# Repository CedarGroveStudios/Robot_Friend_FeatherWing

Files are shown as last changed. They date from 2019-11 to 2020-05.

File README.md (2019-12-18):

# Cedar Grove Robot Friend FeatherWing

### _A passive FeatherWing adapter for stacking an Adafruit PyBadge or PyGamer onto a Crickit FeatherWing. Includes a prototyping area for custom circuitry and sensors._

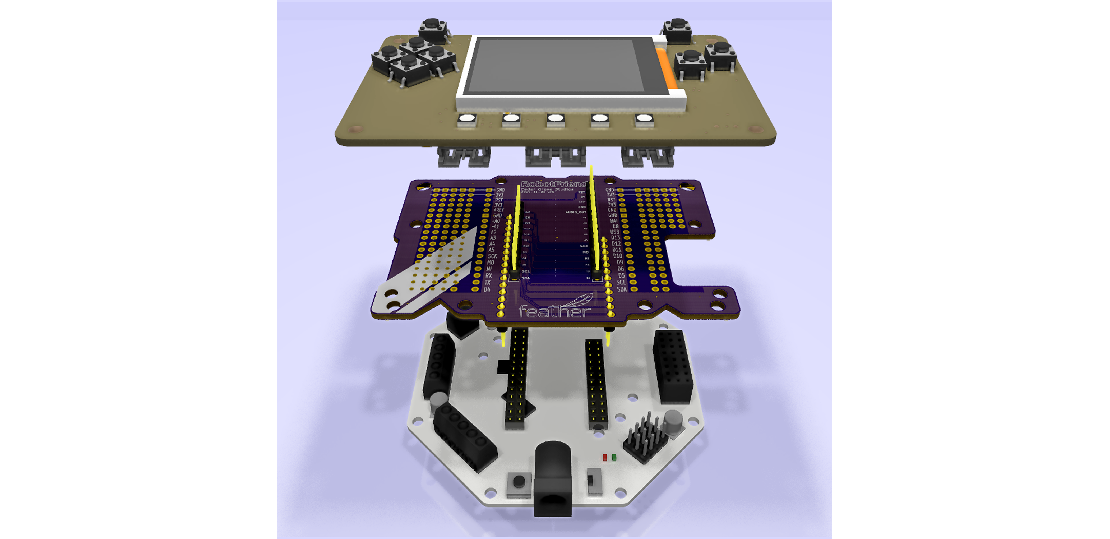
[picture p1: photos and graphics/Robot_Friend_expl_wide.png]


Perched on the top of a robot chassis, the Cedar Grove Robot Friend FeatherWing passively connects the FeatherWing connections of a PyBadge or PyGamer device with a Crickit FeatherWing. The Crickit provides 3.3V power to the attached PyBadge/PyGamer. All Feather signals are interconnected to accommodate custom alterations to the Crickit module, such as support for IRQ/Busy or sensor modifications.

The Cedar Grove Robot Friend includes a prototype area and a breakout of all Feather pins for further cusomization.

For use ONLY with the Crickit FeatherWing and compatible Feather MCU boards. To date, it has only been tested with the PyGamer and PyBadge. Double-check pin compatibility if you plan to attach or stack other Feather devices.

#### Caution:
The Crickit is capable of providing up to 150mA of 3.3-volt power to the attached PB/PG Feather. In normal operation without any of the NeoPixels lighted or the use of the built-in speaker amplifier, the PB/PG will draw about 60mA from the Crickit's internal 3.3-volt regulator. 

When the PB/PG is powered only by the Crickit via the Feather 3V pin, the PB/PG 3.3v regulator is reverse-biased by the Crickit-supplied +3.3 volts. The AP2112-3.3 regulator has an intrinsic MOSFET diode between its output and input that conducts when reverse-biased, raising the voltage of the input pin to the same as the output pin less the forward voltage drop of the diode. What that means is that 5-volt components like the PB/PG's NeoPixels and Stemma connectors will have approximately +3.2 volts available for operation. The PB/PG NeoPixels seem to work with the lower voltage, but might not be 100% reliable. 

Since the reverse-biased "feature" of the PB/PG's internal regulator is not documented in the datasheet, it's probably a good idea to limit use of the PB/PG NeoPixels when stacked on the Crickit via the Robot Friend FeatherWing. If you need to brightly light the PB/PG NeoPixels or connect a speaker to the on-board amplifier, consider adding a small LiPo battery directly to the PB/PG or just use the Crickit's on-board NeoPixel or drive a string via the Crickit's external NeoPixel connector. If a louder speaker is needed, use the Crickit's speaker output since the Crickit amplifier is not connected to the 3.3-volt power supply.

Intrinsic MOSFET Diode Discussion: https://www.digikey.com/en/articles/techzone/2016/sep/the-significance-of-the-intrinsic-body-diodes-inside-mosfets

OSH Park project: 

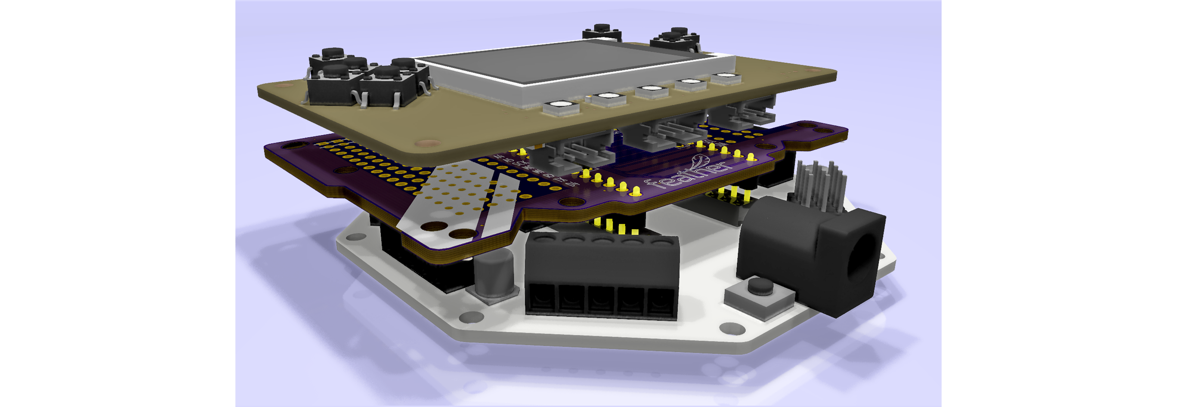
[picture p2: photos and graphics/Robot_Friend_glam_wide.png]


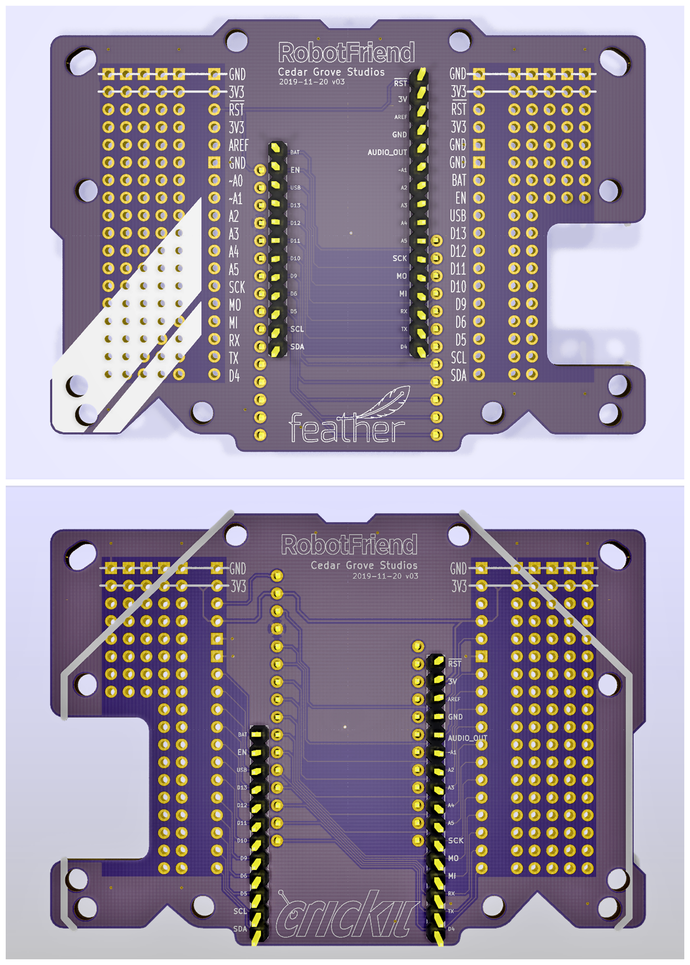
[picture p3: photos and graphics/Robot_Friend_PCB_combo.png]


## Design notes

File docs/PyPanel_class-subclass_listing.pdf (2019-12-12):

### PyPanel Class-Subclass Listing

board | i2c | panel | display | crickit | terminalio | label | displayio | turtle | stemma (list)
A0 | deinit | acceleration | auto_brightness | continuous_servo_1 | FONT | displayio Bitmap | addshape | device
A1 | readfrom_into | auto_dim_display | brightness | continuous_servo_2 | Terminal | Label | ColorConverter | back | object
A2 | scan | bitmap_qr | bus | continuous_servo_3 | | | Disiplay | backward | description
A3 | try_lock | brightness | height | continuous_servo_4 | | | FourWire | bk
A4 | unlock | button | refresh_soon | dc_motor_1 | | | Group | circle
A5 | writeto | BUTTON_A | show | dc_motor_2 | | | OnDiskBitmap | clear
A6 | | BUTTON_B | wait_for_frame | drive_1 | | | Palette | degrees
A7 | | BUTTON_DOWN | width | drive_2 | | | ParallelBus | dot
A8 | | BUTTON_LEFT | | drive_3 | | | release_displays | down
A9 | | BUTTON_RIGHT | | drive_4 | | | Shape | fd
ACCELEROMETER_INTERRUPT | | BUTTON_SELECT | | drive_stepper_motor | | | TileGrid | forward
BUTTON_CLOCK | | BUTTON_START | | feather_drive_1 | | | | getpen
BUTTON_LATCH | | BUTTON_UP | | feather_drive_2 | | | | goto
BUTTON_OUT | | joystick (PyGamer only) | | feather_drive_3 | | | | heading
D0 | | has_joystick | | feather_drive_4 | | | | home
D1 | | light | | feather_drive_stepper_motor | | | | ht
D10 | | pixels | | init_neopixel | | | | isdown
D11 | | play_file | | neopixel | | | | left
D12 | | play_tone | | onboard_pixel | | | | lt
D13 | | show_badge | | reset | | | | pd
D2 | | show_business_card | | seesaw | | | | pencolor
D3 | | show_qr_code | | servo_1 | | | | pendown
D4 | | show_terminal | | servo_2 | | | | pensize
D5 | | start_tone | | servo_3 | | | | penup
D6 | | stop_tone | | servo_4 | | | | position
D7 | | | | SIGNAL1 | | | | pu
D8 | | | | SIGNAL2 | | | | radians
D9 | | | | SIGNAL3 | | | | right
DISPLAY | | | | SIGNAL4 | | | | rt
I2C | | | | SIGNAL5 | | | | seth
LIGHT | | | | SIGNAL6 | | | | setheading
MISO | | | | SIGNAL7 | | | | setpos
MOSI | | | | SIGNAL8 | | | | setposition
NEOPIXEL | | | | stepper_motor | | | | setx
RX | | | | touch_1 | | | | sety
SCK | | | | touch_2 | | | | st
SCL | | | | touch_3 | | | | turtlesize
SDA | | | | touch_4 | | | | up
SPEAKER | | | | | | | | width
SPEAKER_ENABLE | | | | | | | | xcor
SPI | | | | | | | | ycor
TFT_CS
TFT_DC
TFT_LITE
TFT_MOSI
TFT_RST
TFT_SCK
TX
UART
12/12/2019 11:58 AM | PyPanel_class-subclass_listing.xlsx top_level | Page 1 of 1

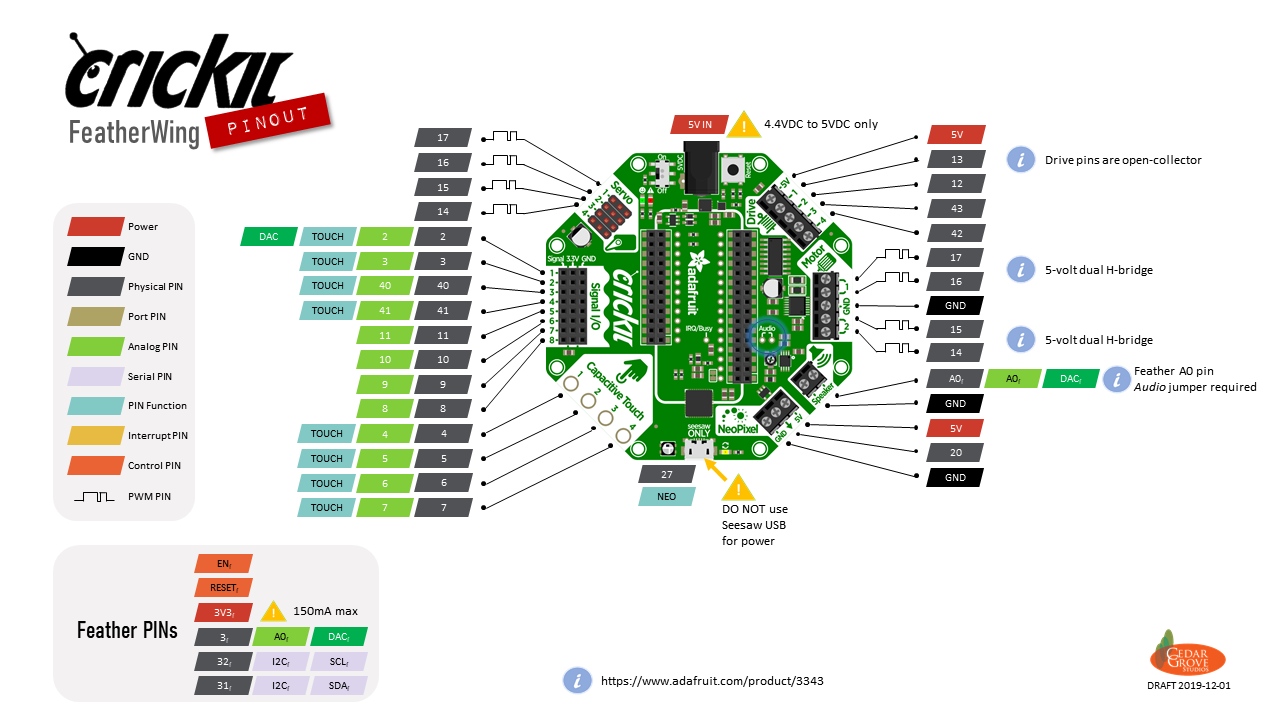
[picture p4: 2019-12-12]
docs/Crickit_FeatherWing_pinout.png

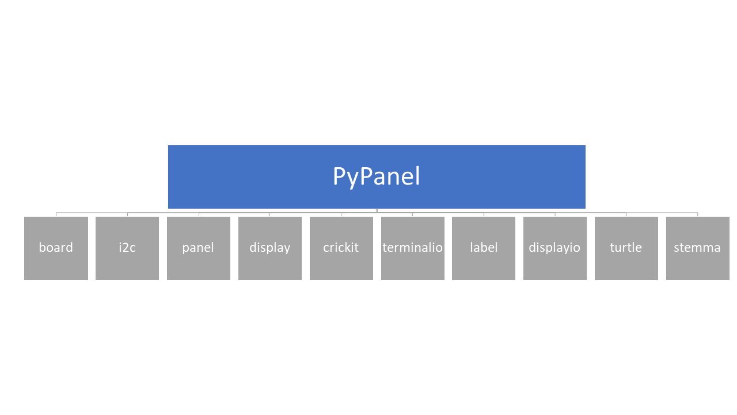
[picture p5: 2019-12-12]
docs/PyPanel_feature_hierarchy.png

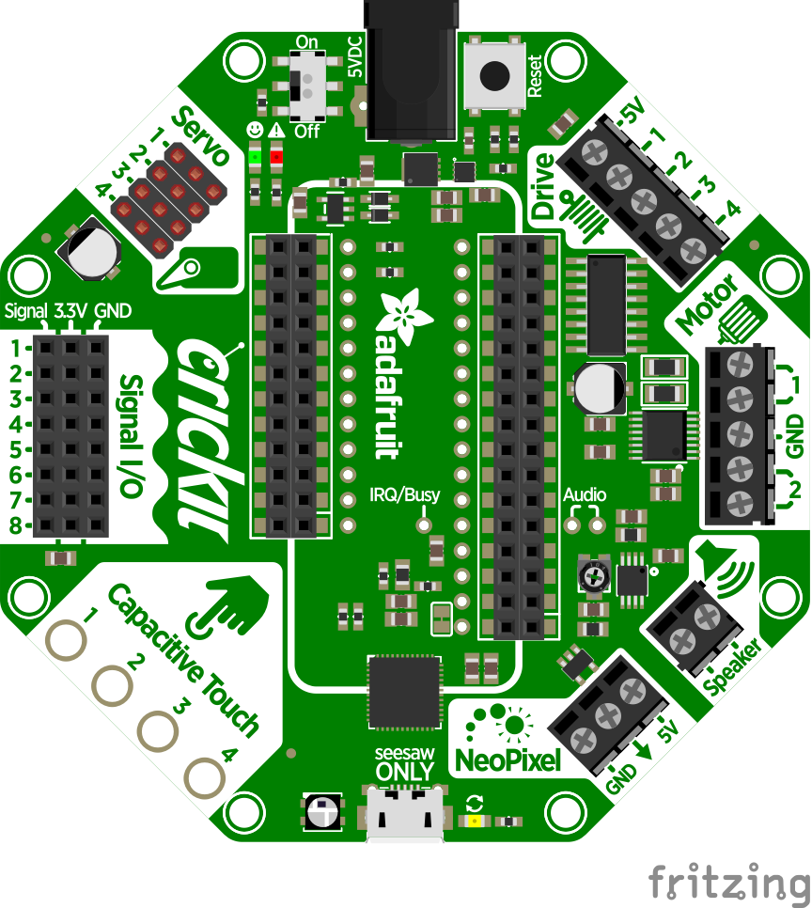
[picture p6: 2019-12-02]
docs/Untitled Sketch_bb.png

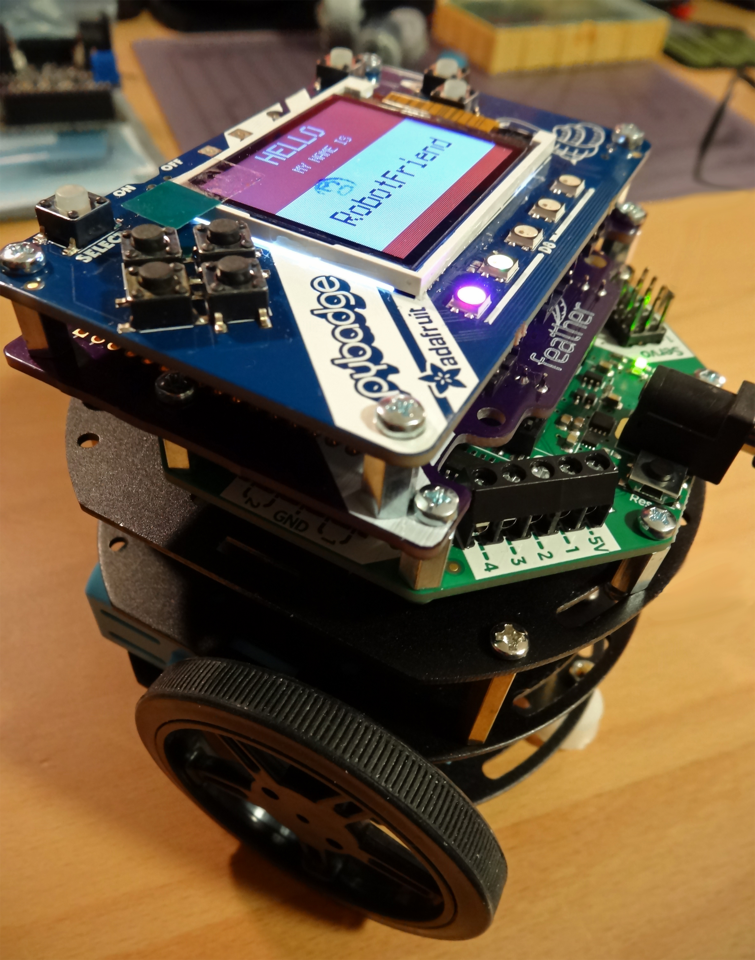
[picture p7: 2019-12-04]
photos and graphics/DSC05909a.jpg

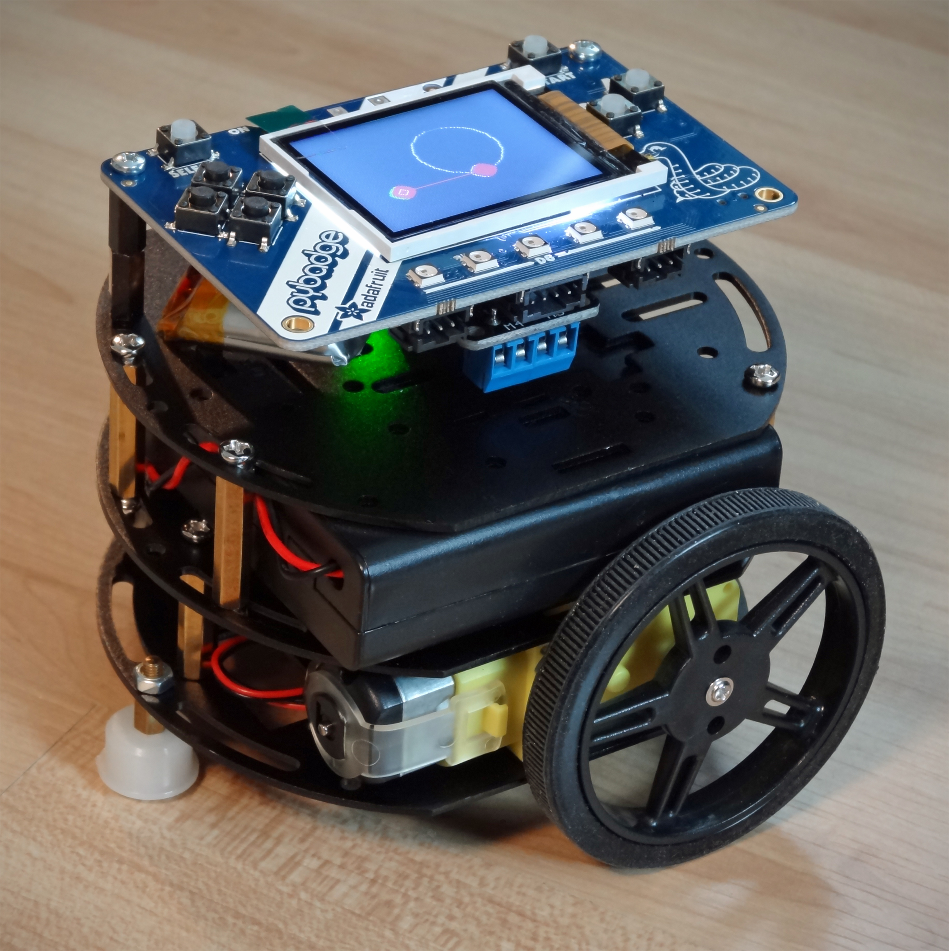
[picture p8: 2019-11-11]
photos and graphics/DSC05840a lores.jpg

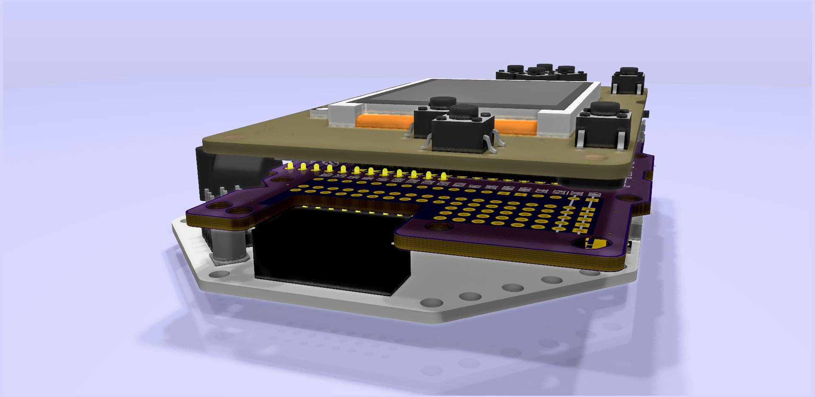
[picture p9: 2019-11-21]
photos and graphics/Robot_Friend_cutout.png

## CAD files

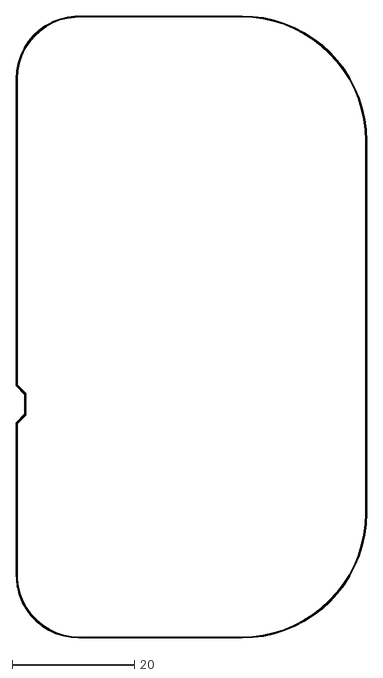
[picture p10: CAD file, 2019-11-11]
photos and graphics/Adafruit PyGamer-Edge.Cuts.dxf
57.3 x 101.8

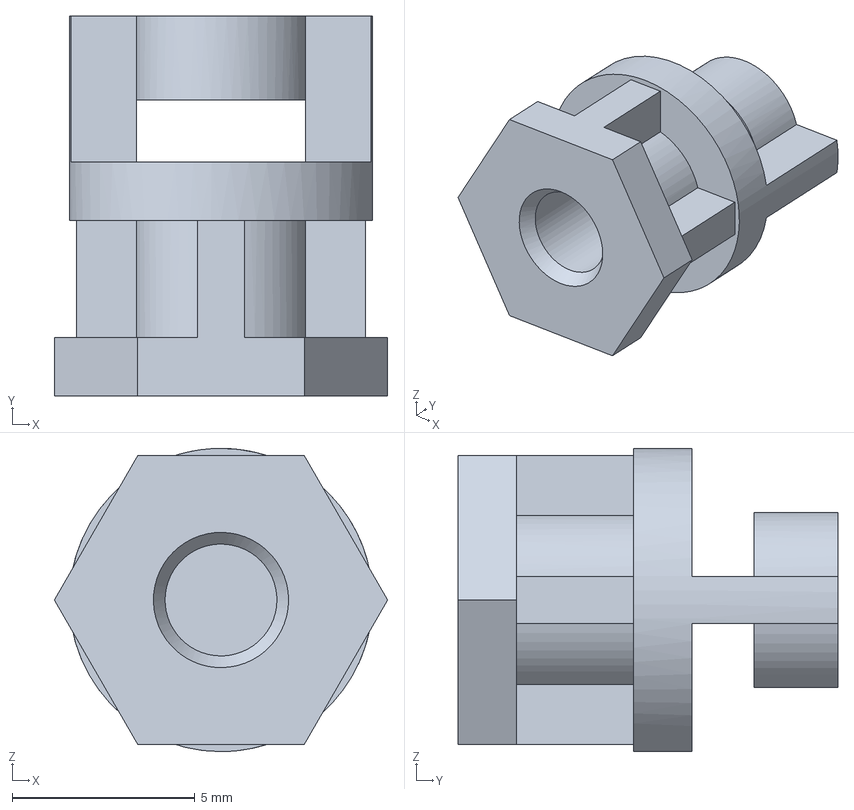
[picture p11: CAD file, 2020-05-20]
TCEHCBS board fastener/TCEHCBS-4-01.stp
9.12 x 10.4 x 8.30 mm

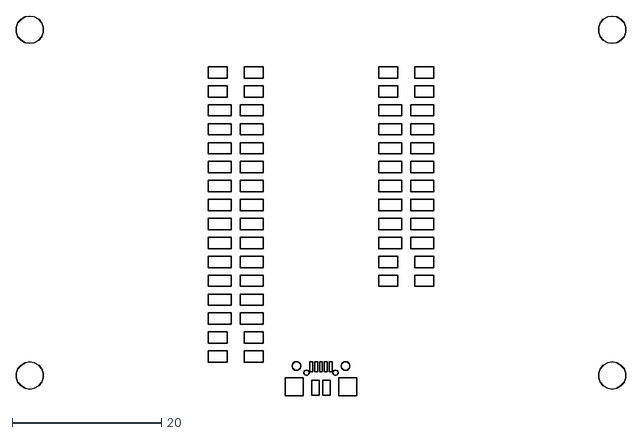
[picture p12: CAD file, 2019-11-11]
photos and graphics/Adafruit PyBadge-Bottom.dxf
81.7 x 50.9

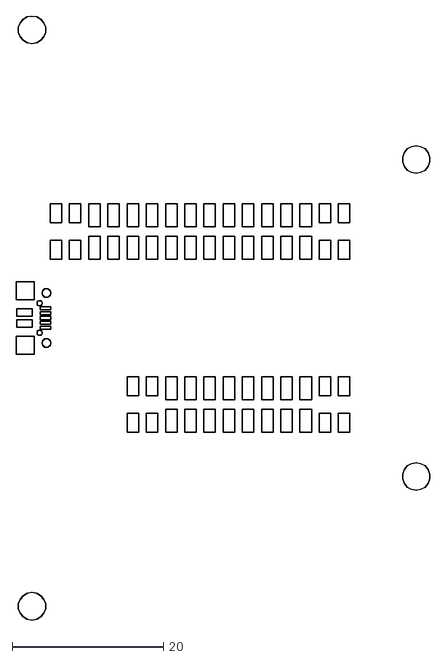
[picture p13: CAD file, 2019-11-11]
photos and graphics/Adafruit PyGamer-Bottom.dxf
54.7 x 79.9

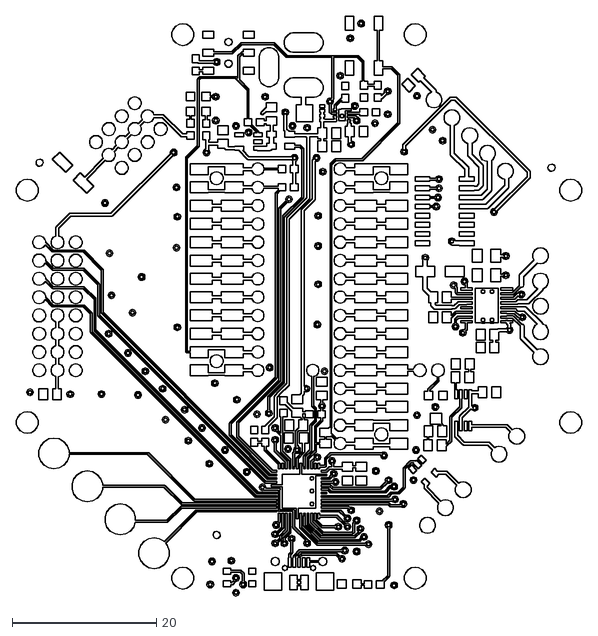
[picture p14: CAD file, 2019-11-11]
photos and graphics/Adafruit Crickit FeatherWing-Top.dxf
78.4 x 80.5

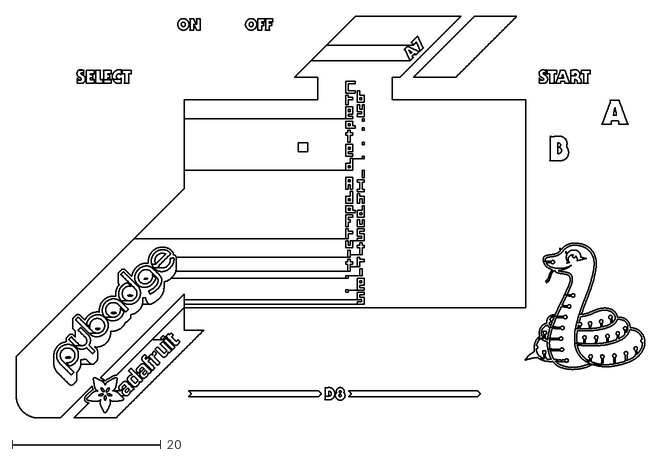
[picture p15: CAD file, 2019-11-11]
photos and graphics/Adafruit PyBadge-Dwgs.User.dxf
84.6 x 54.1

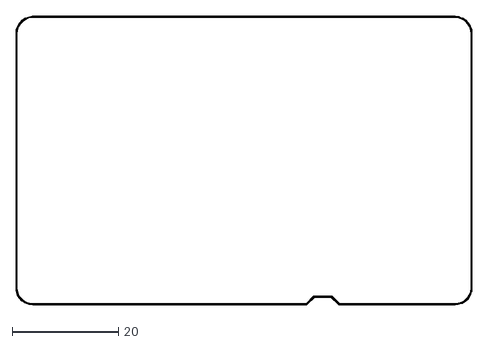
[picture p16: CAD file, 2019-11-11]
photos and graphics/Adafruit PyBadge-Edge.Cuts.dxf
85.9 x 54.3

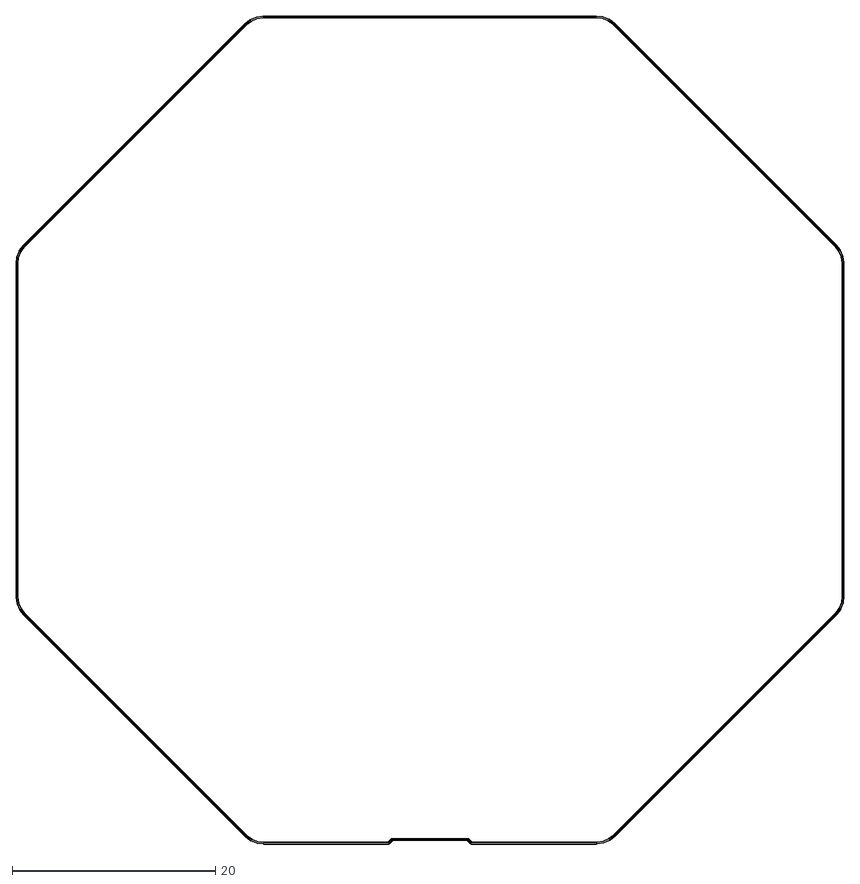
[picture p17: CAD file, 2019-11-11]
photos and graphics/Adafruit Crickit FeatherWing-Edge.Cuts.dxf
81.4 x 81.4

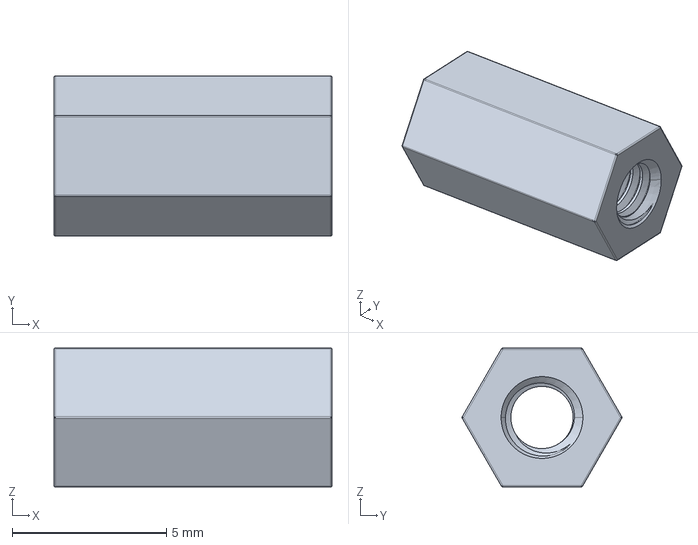
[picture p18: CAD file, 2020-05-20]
Mouser_M1256-2545-N-9mm_M2.5_standoff/M1256-2545-N-Choose_material.stp
9.00 x 5.18 x 4.50 mm

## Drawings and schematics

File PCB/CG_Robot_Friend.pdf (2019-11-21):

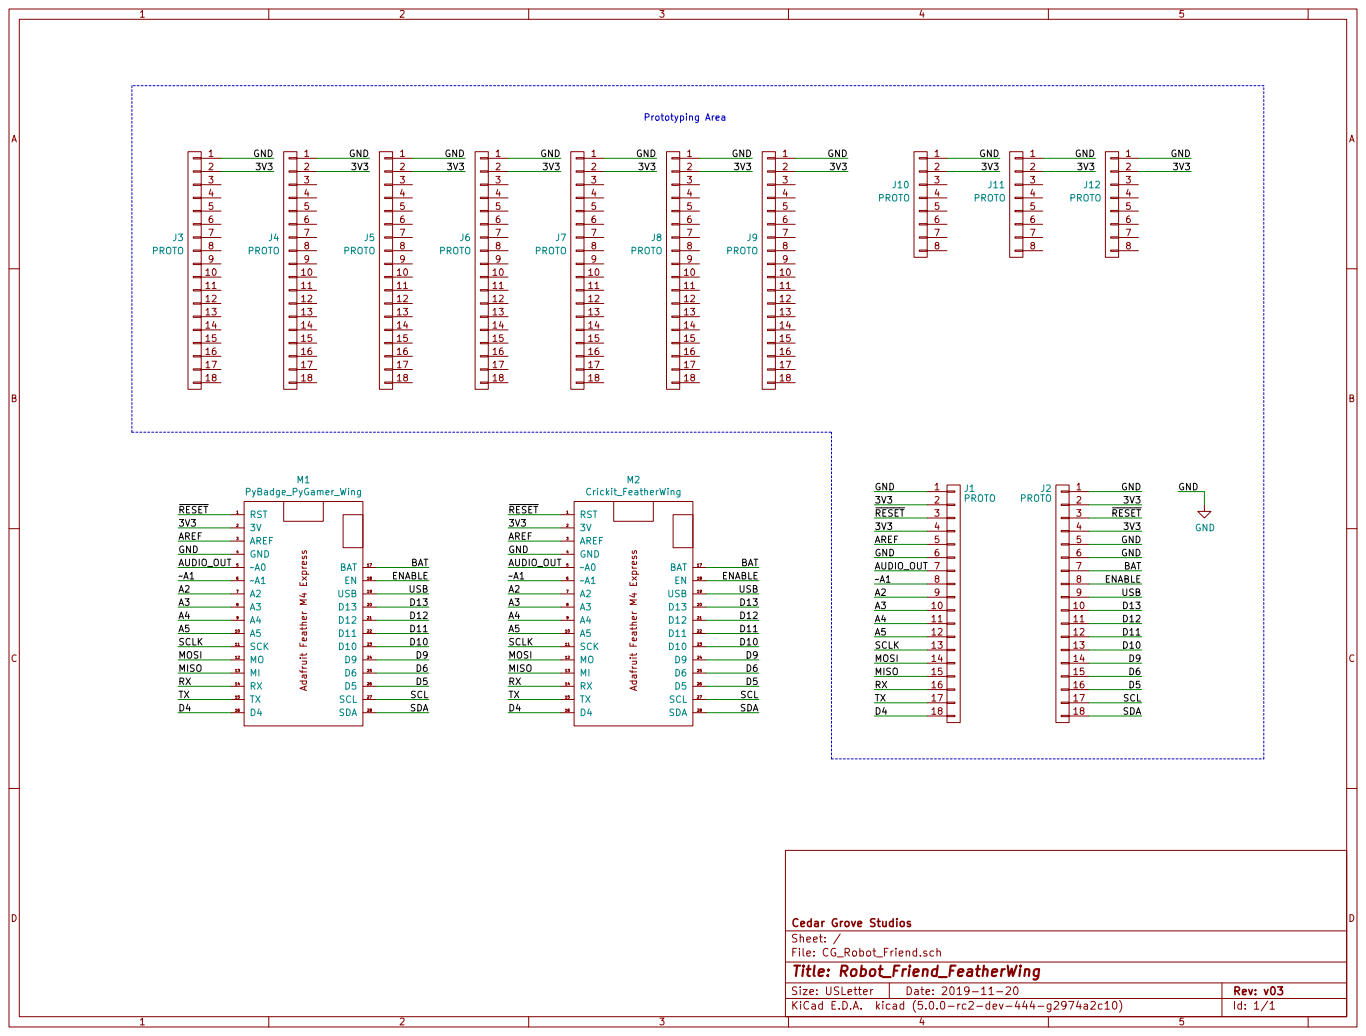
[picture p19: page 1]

SCL ENABLE D13 USB D11 D12 D9 D10 D5 D6 BAT MOSI SCLK

File: CG_Robot_Friend.sch Sheet: / Cedar Grove Studios SDA

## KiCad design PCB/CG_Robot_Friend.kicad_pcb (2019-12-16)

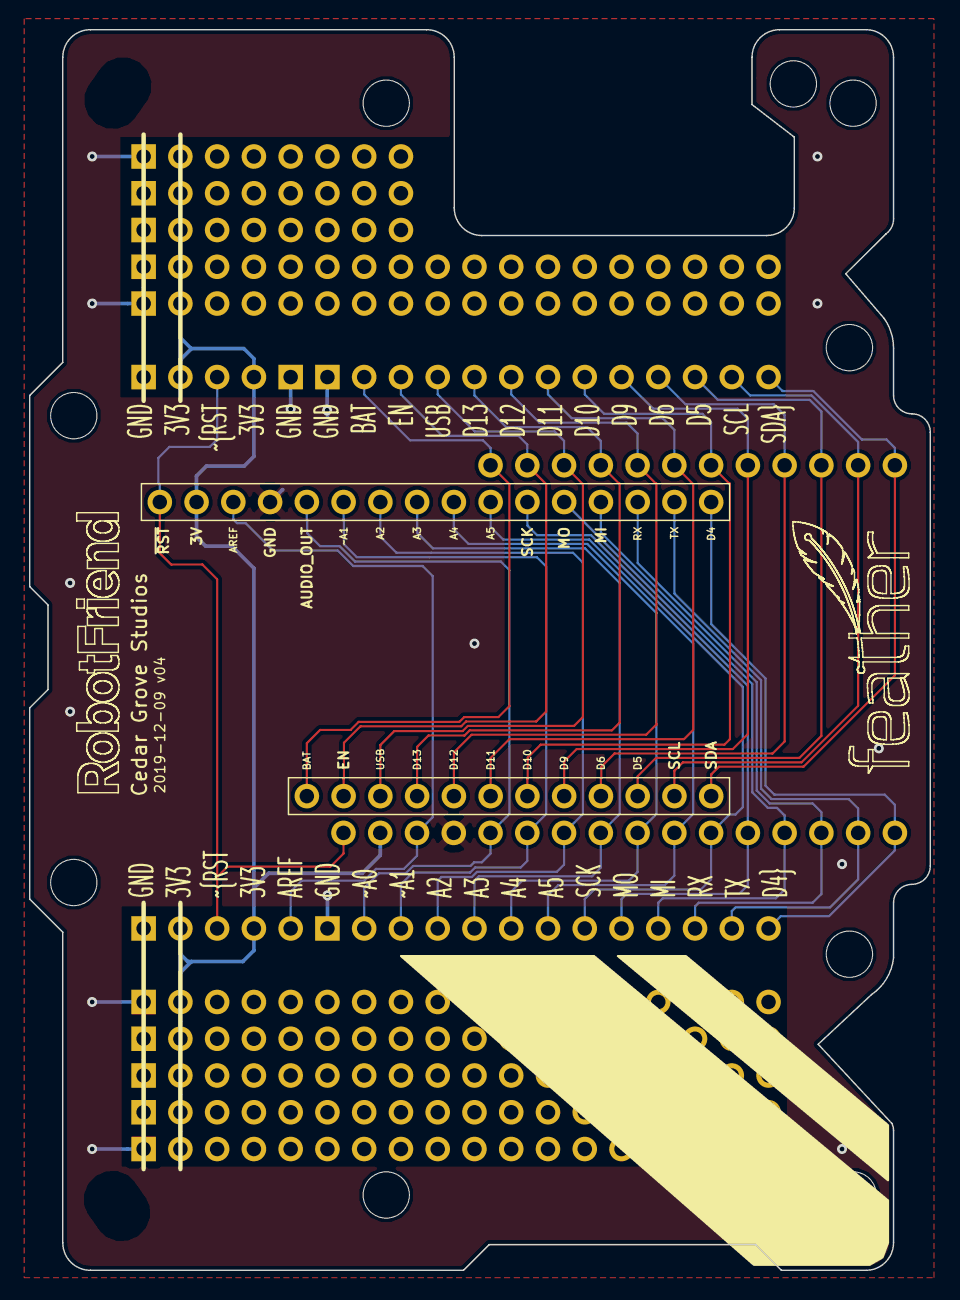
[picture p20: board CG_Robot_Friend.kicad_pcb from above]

Board: 2 copper layers, 62.2 x 85.7 mm, 14 parts (1 on the bottom side), 28 nets.

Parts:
J1, J2, J3, J4, J5, J6, J7, J8, J9: PROTO; Pin_Header_Straight_1x18_Pitch2.54mm_nosilk
J10, J11, J12: PROTO; Pin_Header_Straight_1x08_Pitch2.54mm_no_silk
M1: PyBadge_PyGamer_Wing; Adafruit_PyBadge_PyGamer_Wing_conn_no_mounting_holes
M2: Crickit_FeatherWing; Adafruit_Crickit_Flip_no_mounting_holes

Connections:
/3V3: J1.2, J1.4, J2.2, J2.4, J3.2, J4.2, J5.2, J6.2, J7.2, J8.2, J9.2, J10.2, J11.2, J12.2, M1.2, M2.2
/A2: J1.9, M1.7, M2.7
/A3: J1.10, M1.8, M2.8
/A4: J1.11, M1.9, M2.9
/A5: J1.12, M1.10, M2.10
/AREF: J1.5, M1.3, M2.3
/AUDIO_OUT: J1.7, M1.5, M2.5
/BAT: J2.7, M1.17, M2.17
/D4: J1.18, M1.16, M2.16
/D5: J2.16, M1.26, M2.26
/D6: J2.15, M1.25, M2.25
/D9: J2.14, M1.24, M2.24
/D10: J2.13, M1.23, M2.23
/D11: J2.12, M1.22, M2.22
/D12: J2.11, M1.21, M2.21
/D13: J2.10, M1.20, M2.20
/ENABLE: J2.8, M1.18, M2.18
/MISO: J1.15, M1.13, M2.13
/MOSI: J1.14, M1.12, M2.12
/RX: J1.16, M1.14, M2.14
/SCL: J2.17, M1.27, M2.27
/SCLK: J1.13, M1.11, M2.11
/SDA: J2.18, M1.28, M2.28
/TX: J1.17, M1.15, M2.15
/USB: J2.9, M1.19, M2.19
/~RESET: J1.3, J2.3, M1.1, M2.1
/~~A1: J1.8, M1.6, M2.6
GND: J1.1, J1.6, J2.1, J2.5, J2.6, J3.1, J4.1, J5.1, J6.1, J7.1, J8.1, J9.1, J10.1, J11.1, J12.1, M1.4, M2.4

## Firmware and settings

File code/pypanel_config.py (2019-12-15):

config = {
	'mcp4725' : {
		'name'     : 'MCP4725',
		'desc'     : '12-bit DAC',
		'import'   : 'import adafruit_mcp4725',
		'instance' : 'mcp4725 = adafruit_mcp4725.MCP4725(i2c)',
		'test'     : 'mcp4725.normalized_value = 0.0'
		},

	'ssd1306' : {
		'name'     : 'SSD1306',
		'desc'     : '128x 32 OLED',
		'import'   : 'import adafruit_ssd1306',
		'instance' : 'ssd1306 = adafruit_ssd1306.SSD1306_I2C(128, 32, i2c)',
		'test'     : 'ssd1306.fill(0)'
		},

	'crickit' : {  # needs to be last I2C device; locks bus
		'name'     : 'Crickit',
		'desc'     : 'Crickit Wing',
		'import'   : 'from adafruit_crickit import crickit',
		'instance' : 'crickit.init_neopixel(1, brightness=0.01)',
		'test'     : 'crickit.onboard_pixel.brightness = 0.01'
		}
}

"""
	class : {
		'name'     : name,
		'desc'     : description,
		'import'   : import string to execute,
		'instance' : instance string to execute,
		'test'     : test string to execute
		}
"""

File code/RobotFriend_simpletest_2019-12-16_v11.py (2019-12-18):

# RobotFriend_simpletest_2019-12-16_v11.py
# uses revised adafruit_pybadger and adafruit_crickit
# uses cedargrove_pypanel to abstract Crickit and PyBadge/PyGamer

import time
import random as rand
from cedargrove_pypanel import *

for i in range(0,3): print(" ")
if panel.has_joystick: print("Joystick found")  # if PyGamer
else: print("No joystick")

test_delay = 0.25  # seconds between tests

print(" ")
print("Stemma devices found:")
for i in range(0, len(stemma)):
    print("%s : %s" % (stemma[i][0], stemma[i][2]))
if len(stemma) == 0: print("--none--")
print(" ")
time.sleep(2)

try:
    mcp4725.normalized_value = 0.5  # set DAC output to mid-scale
except: pass

try:
    ssd1306.text("RobotFriend", 0, 8, 1)
    ssd1306.show()
except: pass

# set Crickit on-board NeoPixel to purple
crickit.onboard_pixel[0] = (255, 24, 255)
# or
crickit.onboard_pixel.fill((255, 24, 255))

# PyBadge test
panel.pixels.fill((255, 24, 255))  # dim purple neopixels
panel.brightness = 0.9  # set initial display brightness
panel.show_badge(name_string="RobotFriend", hello_scale=2, my_name_is_scale=1, name_scale=2)
time.sleep(test_delay)
panel.show_terminal()

# Text area test
# Set text, font, and color
text = "HELLO WORLD"
font = terminalio.FONT
# font = pp.bitmap_font.load_font("/Helvetica-Bold-16.bdf")
color = 0x0000FF
# Create the text label
text_area = label.Label(font, text="HELLO WORLD", color=0x00FF00)
# Set the location
text_area.x = 50
text_area.y = 60
# Show it
display.show(text_area)
time.sleep(test_delay)

# Bitmap graphics test
with open("/RobotFriend_tiny.bmp", "rb") as bitmap_file:
    # Setup the file as the bitmap data source
    bitmap = displayio.OnDiskBitmap(bitmap_file)
    # Create a TileGrid to hold the bitmap
    tile_grid = displayio.TileGrid(bitmap, pixel_shader=displayio.ColorConverter())
    # Create a Group to hold the TileGrid
    group = displayio.Group()
    # Add the TileGrid to the Group
    group.append(tile_grid)
    # Add the Group to the Display
    display.show(group)
    display.wait_for_frame()
    time.sleep(test_delay)

# Turtle graphics test
def hilbert2(step, rule, angle, depth, t):
    if depth > 0:
        a = lambda: hilbert2(step, "a", angle, depth - 1, t)
        b = lambda: hilbert2(step, "b", angle, depth - 1, t)
        left = lambda: t.left(angle)
        right = lambda: t.right(angle)
        forward = lambda: t.forward(step)
        if rule == "a":
            left(); b(); forward(); right(); a(); forward(); a(); right(); forward(); b(); left()
        if rule == "b":
            right(); a(); forward(); left(); b(); forward(); b(); left(); forward(); a(); right()

turtle = turtle(board.DISPLAY)
turtle.penup()

turtle.goto(-45, -45)
turtle.pendown()
hilbert2(6, "a", 90, 4, turtle)

time.sleep(test_delay)

# Robot-turtle helpers
def robot_forward(dist=0, speed=1.0):
    turtle.forward(dist * 10)
    crickit.dc_motor_1.throttle = speed
    crickit.dc_motor_2.throttle = speed
    time.sleep(dist)
    crickit.dc_motor_1.throttle = 0
    crickit.dc_motor_2.throttle = 0

def robot_backward(dist=0, speed=1.0):
    turtle.backward(dist * 10)
    crickit.dc_motor_1.throttle = speed * -1.0
    crickit.dc_motor_2.throttle = speed * -1.0
    time.sleep(dist)
    crickit.dc_motor_1.throttle = 0
    crickit.dc_motor_2.throttle = 0

def robot_left(dist=0, speed=1.0):
    turtle.left(90)
    crickit.dc_motor_1.throttle = speed * -1.0
    crickit.dc_motor_2.throttle = speed
    time.sleep(0.25)
    crickit.dc_motor_1.throttle = 0
    crickit.dc_motor_2.throttle = 0
    robot_forward(dist, speed)

def robot_right(dist=0, speed=1.0):
    turtle.right(90)
    crickit.dc_motor_1.throttle = speed
    crickit.dc_motor_2.throttle = speed * -1.0
    time.sleep(0.25)
    crickit.dc_motor_1.throttle = 0
    crickit.dc_motor_2.throttle = 0
    robot_forward(dist, speed)

turtle.penup()
turtle.clear()
turtle.goto(0, 0)
time.sleep(test_delay)
turtle.pendown()
robot_forward(1)
robot_backward(1)
robot_left(1)
robot_right(1)

# test of solenoid on drive_1
crickit.feather_drive_1.fraction = 1.0
time.sleep(0.1)
crickit.feather_drive_1.fraction = 0.0

# test of Servo 1
crickit.servo_1.angle = 90
time.sleep(test_delay)
crickit.servo_1.angle = 0
time.sleep(test_delay)
crickit.servo_1.angle = 180
time.sleep(test_delay)

print("RobotFriend_simpletest_2019-12-16_v11.py")
print("----------------------------------------")

# Wave file to speaker test
panel.play_tone(440, 0.25)
time.sleep(0.25)
panel.play_file("rimshot.wav")
time.sleep(test_delay)

t1 = time.time()
select_state = True
light_sensor = panel.light / 65536
panel.show_terminal()

while True:
    t2 = time.monotonic()

    if panel.button.select:
        if select_state:
            panel.show_badge(name_string="RobotFriend", hello_scale=2, my_name_is_scale=1, name_scale=2)
        else:
            panel.show_terminal()
        while panel.button.select:
            time.sleep(0.1)  # allow button to release
        select_state = not(select_state)

    print("----------")
    panel.pixels.fill([0, 0, 0])
    if panel.has_joystick:
        print("Joystick:", panel.joystick)  # if PyGamer

    # print(panel.button)  # to show state of buttons

    light_sensor = ((panel.light / 65536) + light_sensor) /2
    x, y, z = panel.acceleration
    print("Time:%6.0f, Light:%1.2f" % (t2, light_sensor))
    print("X:%2.1f, Y:%2.1f, Z:%2.1f" % (x, y, z))
    # scale and format for plotter
    print((int(light_sensor * 100) / 100, int(x * 10) / 100,
           int(y * 10) / 100, int(z * 10) / 100))

    rgb = [rand.randint(64, 255), rand.randint(64, 255), rand.randint(64, 255)]
    panel.pixels[int(t2) % 5] = rgb
    crickit.onboard_pixel[0]  = rgb

    panel.auto_dim_display(delay=20, movement_threshold=1)

    time.sleep(test_delay)

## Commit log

2019-11-11 initial repo load
    [Adafruit Crickit FeatherWing-Edge.Cuts.dxf, Adafruit Crickit FeatherWing-Top.dxf, Adafruit PyBadge-Bottom.dxf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]
2019-11-12 update to v03
    [CG_Robot_Friend-B.Cu.gbl, CG_Robot_Friend-B.Mask.gbs, CG_Robot_Friend-B.SilkS.gbo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]
2019-11-12 photos of prototype
2019-11-21 update mechanical PCB design
    to open up a few of the hidden Crickit connectors
    [CG_Robot_Friend-B.Cu.gbl, CG_Robot_Friend-B.Mask.gbs, CG_Robot_Friend-B.SilkS.gbo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]
2019-11-21 Update for PCB version 03
    [CG_Robot_Friend-B.Cu.gbl, CG_Robot_Friend-B.Mask.gbs, CG_Robot_Friend-B.SilkS.gbo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]
2019-12-10 update to PCB v04: enhance cutout
    [CG_Robot_Friend-B.Cu.gbl, CG_Robot_Friend-B.Mask.gbs, CG_Robot_Friend-B.SilkS.gbo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]
2019-12-10 update to v04
    [CG_Robot_Friend.kicad_pcb]
2019-12-11 update tests and PyPanel library
    [PyPanel_class-subclass_listing.xlsx]
2019-12-11 update test and pypanel library
    [PyPanel_class-subclass_listing.xlsx]
2019-12-12 update docs
    [PyPanel_class-subclass_listing.xlsx]
2019-12-15 update device discovery code
2019-12-16 updated PCB layout for I/O connector
    [CG_Robot_Friend-B.Cu.gbl, CG_Robot_Friend-B.Mask.gbs, CG_Robot_Friend-B.SilkS.gbo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]
2019-12-18 add RTC wing to device catalog
2020-05-20 update supporting documentation
    [M1256-2545-N-Choose_material.stp, TCEHCBS-4-01.stp]
2021-07-12 update documentation
    [PyPanel_class-subclass_listing.xlsx]
